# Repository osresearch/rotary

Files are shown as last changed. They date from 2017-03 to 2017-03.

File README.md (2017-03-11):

Outbound call state machine

This is an extension on Adafruit's [`FONAtest.ino`](https://github.com/adafruit/Adafruit_FONA/blob/master/examples/FONAtest/FONAtest.ino)
example code to allow it to be used with a rotary phone.  The Teensy
2.0 decodes the pulses and implements the state machine to allow you to
place outbound phone calls.  In-bound calls are working and can activate
the ringer when on USB power, but the boost converter circuit is a work
in progress.

The dialtone is generated by the FONA and under control of the teensy,
but ringing and dialing is done by the cell network.  There is not a
proper "off hook" tone in the FONA, so the closest version was used.

Since the entire phone number must be passed to the `ATDT` command
string, the system must try to detect when the user is done dialing.
There is currently a multi-second delay after the last number.

During a call pulses will be translated to DTMF, but the user will
not hear them on the handset.  There is also no comfort tone, which
makes using the phone feel "dead".

Wiring
===
Inside the phone

* Teensy Gnd -> FONA Ground, FONA Key, Phone F (blue?)
* Teensy Vcc -> FONA Vio
* Teensy Pin 0 -> FONA Reset
* Teensy Pin 1 -> Phone RR (green on the dial), rotary dial
* Teensy Pin 2 -> Phone L1 (RJ45 green), hook relay
* Teensy Pin 6 -> FONA Ring indicator
* Teensy Pin 7 -> FONA RX
* Teensy Pin 8 -> FONA TX
* Teensy Pin 9 -> boost converter pwm
* Teensy Pin A0 -> boost converter voltge divider

The boost converter circuit needs to be drawn.

Note the [FONA 32u4 pinout](https://learn.adafruit.com/adafruit-feather-32u4-fona/pinouts) is a bit different:

* GPIO 8 -> FONA TXD (Soft Serial)
* GPIO 9 -> FONA RXD (Soft Serial)
* GPIO 7 -> FONA Ring Indicator
* GPIO 4 -> FONA Reset

Todo
===
Dialup internet

* Redial support.
* ~~Incoming call state machine~~ - Done. Incoming calls works (although they play a tone in the speaker)
* ~~Disable headset ring tone.~~ - WONTFIX, since the bell overpowers it quite easily.
* Ringer driver circuit. Looks like 15V will engage the bell solenoid, so a simple charge pump and low frequency PWM should do it. -- Almost done, need to find parameters to work with 3.7V LiPo.
* ~~PCB design to mount FONA, Teensy and wire headers for the phone connections. -- Started in `pcb/rotaryfona.sch`, but no where near ready.~~ On hold since the FONA 32u4 has a MCU built in.
* Package everything to fit into the phone.
* Buy a red phone, cut a hole for USB charging cable.
* Teensy powered from the battery?  Battery switch?
* Figure out why 300 baud isn't working with the FONA as well as it did with my cellphone.
* Text to speech for SMS received - only supported in the 800H, not the 800L.

State Machine
==
Rotary Phone State Machine

The rotary phone code is implemented as a state machine to try to
keep it clean and easy to extend. Unfortunately there isn't an easy way
to round trip from the code to this diagram, so it doesn't exactly match
the executable code in [`Rotary.cpp`](./RotaryFona/Rotary.cpp).
Also, nearly every state other than `RINGING` has an implicit edge
back to `ON_HOOK` if the user hangs up the phone while in that state.

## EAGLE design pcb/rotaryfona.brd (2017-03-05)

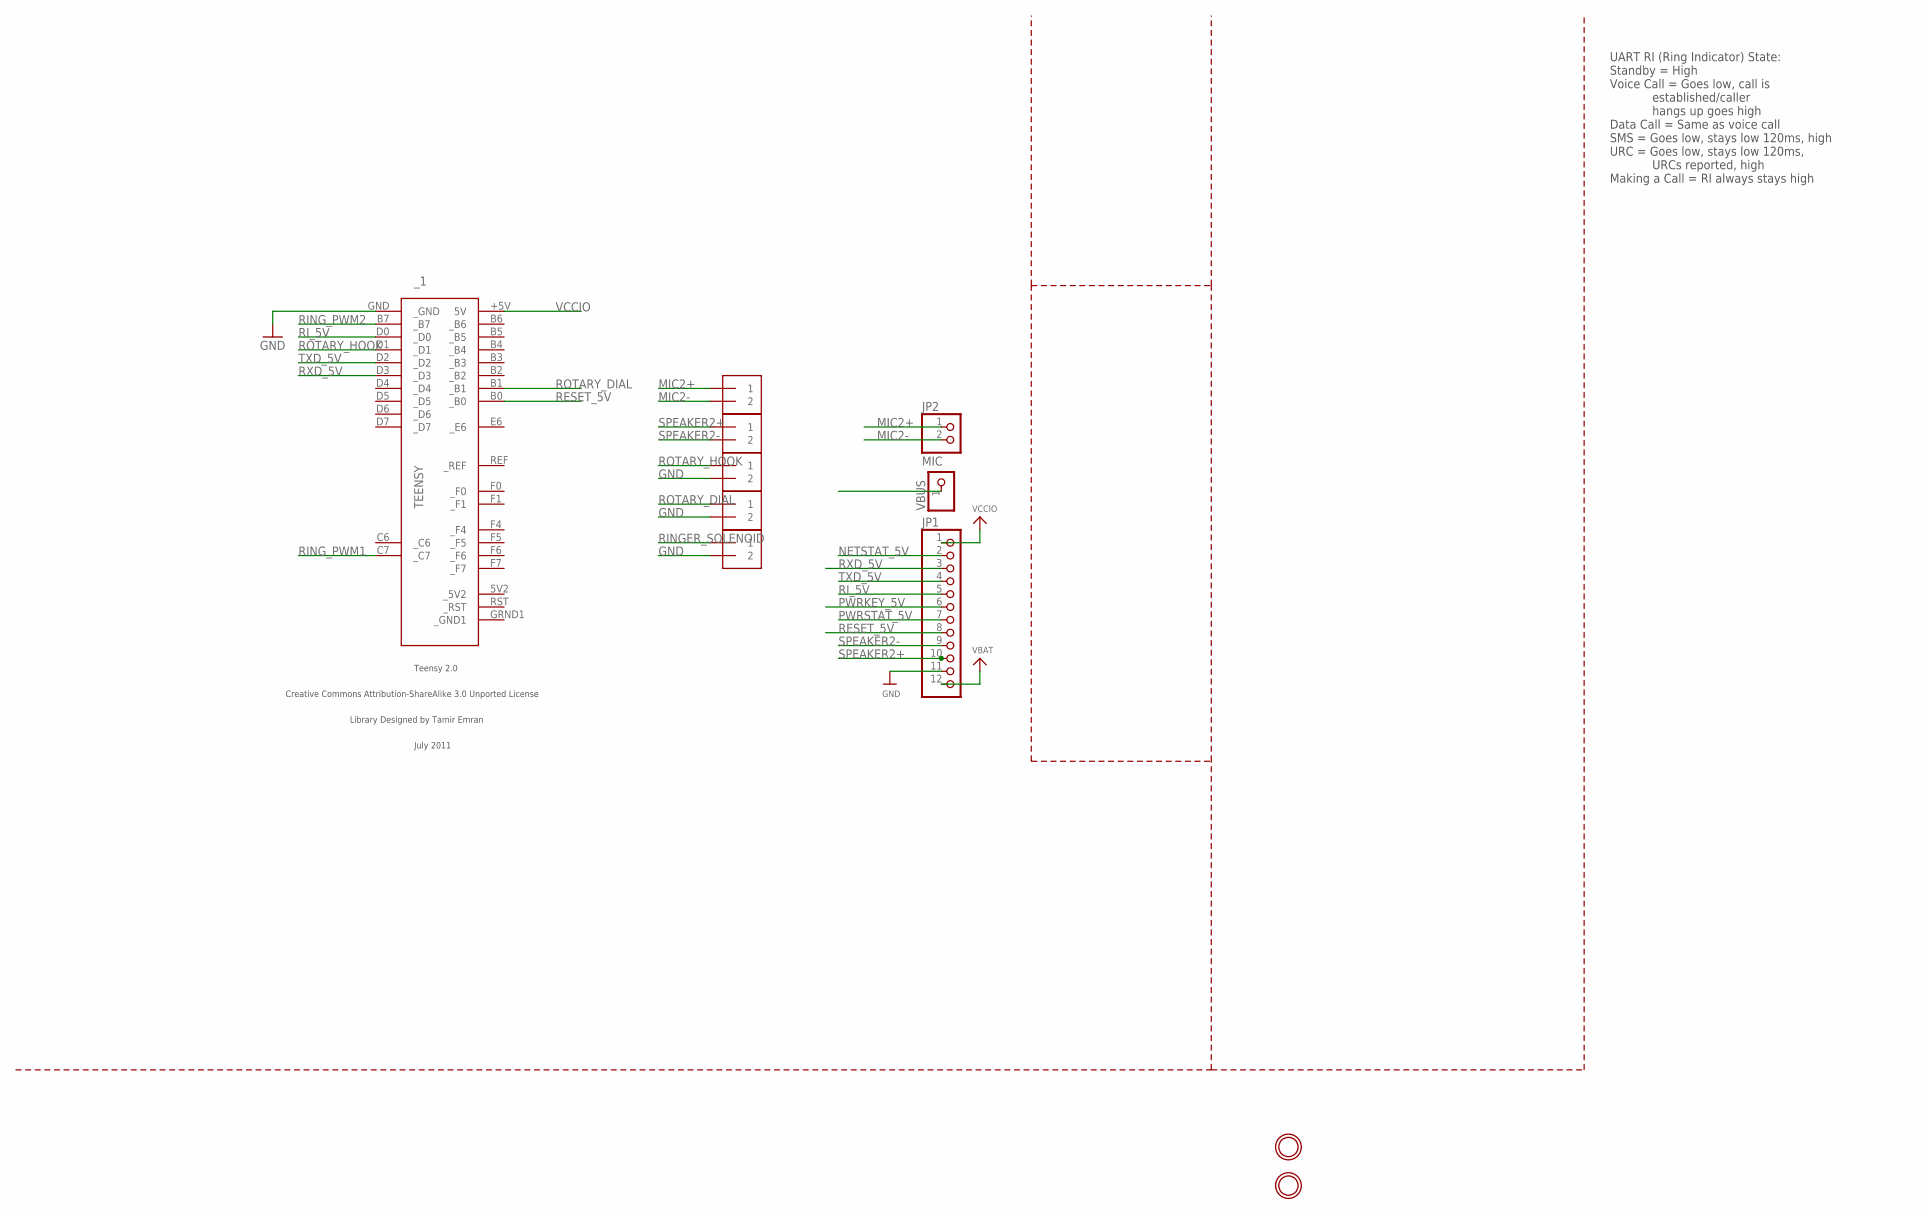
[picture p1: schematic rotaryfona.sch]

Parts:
DIAL: 1X2-3.5MM
HOOK: 1X2-3.5MM
JP1: PINHD-1X12-CB; 1X12-CB
JP2: MIC; 1X02_ROUND
MIC: 1X2-3.5MM
RINGER: 1X2-3.5MM
SPK: 1X2-3.5MM
U$33, U$34: MOUNTINGHOLE2.5; MOUNTINGHOLE_2.5_PLATED
VBUS: PINHD-1X1CB; 1X01-CLEANBIG
_1: TEENSY

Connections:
GND: DIAL.2, HOOK.2, JP1.11, RINGER.2, _1.GND (_GND)
MIC2+: JP2.1, MIC.1
MIC2-: JP2.2, MIC.2
NETSTAT_5V: JP1.2
PWRKEY_5V: JP1.6
PWRSTAT_5V: JP1.7
RESET_5V: JP1.8, _1.B0 (_B0)
RINGER_SOLENOID: RINGER.1
RING_PWM1: _1.C7 (_C7)
RING_PWM2: _1.B7 (_B7)
RI_5V: JP1.5, _1.D0 (_D0)
ROTARY_DIAL: DIAL.1, _1.B1 (_B1)
ROTARY_HOOK: HOOK.1, _1.D1 (_D1)
RXD_5V: JP1.3, _1.D3 (_D3)
SPEAKER2+: JP1.10, SPK.1
SPEAKER2-: JP1.9, SPK.2
TXD_5V: JP1.4, _1.D2 (_D2)
VBAT: JP1.12
VCCIO: JP1.1, _1.+5V (5V)

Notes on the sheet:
UART RI (Ring Indicator) State: Standby = High Voice Call = Goes low, call is established/caller hangs up goes high Data Call = Same as voice call SMS = Goes low, stays low 120ms, high URC = Goes low, stays low 120ms, URCs reported, high Making a Call = RI always stays high

Board: 2 copper layers, 11 parts (0 on the bottom side), 12 nets, no tracks yet.

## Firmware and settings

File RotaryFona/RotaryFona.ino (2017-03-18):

/***************************************************
  This is an extension of Adafruit's FONA example program,
  modified to work with rotary phones like the Bell 500
  and a Teensy microcontroller.

  Designed specifically to work with the Adafruit FONA
  ----> http://www.adafruit.com/products/1946
  ----> http://www.adafruit.com/products/1963
  ----> http://www.adafruit.com/products/2468
  ----> http://www.adafruit.com/products/2542

  These cellular modules use TTL Serial to communicate, 2 pins are
  required to interface
  Adafruit invests time and resources providing this open source code,
  please support Adafruit and open-source hardware by purchasing
  products from Adafruit!

  The rotary phone uses one input pin to detect when the
  handset has gone "off hook" and another to detect the
  pulses of the rotary dial.  The ringer is not yet
  supported.

  Written by Limor Fried/Ladyada for Adafruit Industries
  and Trammell Hudson <hudson@trmm.net>.

  BSD license, all text above must be included in any redistribution
 ****************************************************/

/*
THIS CODE IS STILL IN PROGRESS!

Open up the serial console on the Arduino at 115200 baud to interact with FONA

Note that if you need to set a GPRS APN, username, and password scroll down to
the commented section below at the end of the setup() function.
*/
#include "Adafruit_FONA.h"
#include "Rotary.h"

// Feather Fona 32u4 serial
#define FONA_RX 9
#define FONA_TX 8
#define FONA_RST 4

// this is a large buffer for replies
char replybuffer[255];

// We default to using software serial. If you want to use hardware serial
// (because softserial isnt supported) comment out the following three lines 
// and uncomment the HardwareSerial line
#include <SoftwareSerial.h>
SoftwareSerial fonaSS = SoftwareSerial(FONA_TX, FONA_RX);
SoftwareSerial *fonaSerial = &fonaSS;

// Hardware serial is also possible, but not wired on the
// Feather Fona with the 32u4, so we have to use the software one
//HardwareSerial *fonaSerial = &Serial1;

// Use this for FONA 800 and 808s
Adafruit_FONA fona = Adafruit_FONA(FONA_RST);
// Use this one for FONA 3G
//Adafruit_FONA_3G fona = Adafruit_FONA_3G(FONA_RST);

Rotary rotary(fona);

uint8_t readline(char *buff, uint8_t maxbuff, uint16_t timeout = 0);

uint8_t type;

void setup()
{
#if 0
  // charge pump tuning setup
  rotary.tune();
#else
  rotary.begin();

  //while (!Serial);

  Serial.begin(115200);
  Serial.println(F("FONA basic test"));
  Serial.println(F("Initializing....(May take 3 seconds)"));

  fonaSerial->begin(4800);
  if (! fona.begin(*fonaSerial)) {
    Serial.println(F("Couldn't find FONA"));
    while (1);
  }
  type = fona.type();
  Serial.println(F("FONA is OK"));
  Serial.print(F("Found "));
  switch (type) {
    case FONA800L:
      Serial.println(F("FONA 800L")); break;
    case FONA800H:
      Serial.println(F("FONA 800H")); break;
    case FONA808_V1:
      Serial.println(F("FONA 808 (v1)")); break;
    case FONA808_V2:
      Serial.println(F("FONA 808 (v2)")); break;
    case FONA3G_A:
      Serial.println(F("FONA 3G (American)")); break;
    case FONA3G_E:
      Serial.println(F("FONA 3G (European)")); break;
    default: 
      Serial.println(F("???")); break;
  }
  
  // Print module IMEI number.
  char imei[15] = {0}; // MUST use a 16 character buffer for IMEI!
  uint8_t imeiLen = fona.getIMEI(imei);
  if (imeiLen > 0) {
    Serial.print("Module IMEI: "); Serial.println(imei);
  }

  // Optionally configure a GPRS APN, username, and password.
  // You might need to do this to access your network's GPRS/data
  // network.  Contact your provider for the exact APN, username,
  // and password values.  Username and password are optional and
  // can be removed, but APN is required.
  //fona.setGPRSNetworkSettings(F("your APN"), F("your username"), F("your password"));

  // Optionally configure HTTP gets to follow redirects over SSL.
  // Default is not to follow SSL redirects, however if you uncomment
  // the following line then redirects over SSL will be followed.
  //fona.setHTTPSRedirect(true);


  // setup for the hard wired rotary phone
  fona.setAudio(FONA_EXTAUDIO);
  fona.setMicVolume(FONA_EXTAUDIO, 10);

  printMenu();
#endif
}

void printMenu(void) {
  Serial.println(F("-------------------------------------"));
  Serial.println(F("[?] Print this menu"));
  Serial.println(F("[a] read the ADC 2.8V max (FONA800 & 808)"));
  Serial.println(F("[b] read the Battery V and % charged"));
  Serial.println(F("[C] read the SIM CCID"));
  Serial.println(F("[U] Unlock SIM with PIN code"));
  Serial.println(F("[i] read RSSI"));
  Serial.println(F("[n] get Network status"));
  Serial.println(F("[v] set audio Volume"));
  Serial.println(F("[V] get Volume"));
  Serial.println(F("[H] set Headphone audio (FONA800 & 808)"));
  Serial.println(F("[e] set External audio (FONA800 & 808)"));
  Serial.println(F("[T] play audio Tone"));
  Serial.println(F("[P] PWM/Buzzer out (FONA800 & 808)"));

  // FM (SIM800 only!)
  Serial.println(F("[f] tune FM radio (FONA800)"));
  Serial.println(F("[F] turn off FM (FONA800)"));
  Serial.println(F("[m] set FM volume (FONA800)"));
  Serial.println(F("[M] get FM volume (FONA800)"));
  Serial.println(F("[q] get FM station signal level (FONA800)"));

  // Phone
  Serial.println(F("[c] make phone Call"));
  Serial.println(F("[A] get call status"));
  Serial.println(F("[h] Hang up phone"));
  Serial.println(F("[p] Pick up phone"));

  // SMS
  Serial.println(F("[N] Number of SMSs"));
  Serial.println(F("[r] Read SMS #"));
  Serial.println(F("[R] Read All SMS"));
  Serial.println(F("[d] Delete SMS #"));
  Serial.println(F("[s] Send SMS"));
  Serial.println(F("[u] Send USSD"));
  
  // Time
  Serial.println(F("[y] Enable network time sync (FONA 800 & 808)"));
  Serial.println(F("[Y] Enable NTP time sync (GPRS FONA 800 & 808)"));
  Serial.println(F("[t] Get network time"));

  // GPRS
  Serial.println(F("[G] Enable GPRS"));
  Serial.println(F("[g] Disable GPRS"));
  Serial.println(F("[l] Query GSMLOC (GPRS)"));
  Serial.println(F("[w] Read webpage (GPRS)"));
  Serial.println(F("[W] Post to website (GPRS)"));

  // GPS
  if ((type == FONA3G_A) || (type == FONA3G_E) || (type == FONA808_V1) || (type == FONA808_V2)) {
    Serial.println(F("[O] Turn GPS on (FONA 808 & 3G)"));
    Serial.println(F("[o] Turn GPS off (FONA 808 & 3G)"));
    Serial.println(F("[L] Query GPS location (FONA 808 & 3G)"));
    if (type == FONA808_V1) {
      Serial.println(F("[x] GPS fix status (FONA808 v1 only)"));
    }
    Serial.println(F("[E] Raw NMEA out (FONA808)"));
  }
  
  Serial.println(F("[S] create Serial passthru tunnel"));
  Serial.println(F("-------------------------------------"));
  Serial.println(F(""));

}


void loop() {
  Serial.print(F("FONA> "));
  while (! Serial.available() ) {
    //rotary.loop();

    if (fona.available()) {
      Serial.write(fona.read());
    }
  }

  char command = Serial.read();
  Serial.println(command);


  switch (command) {
    case '?': {
        printMenu();
        break;
      }

    case 'a': {
        // read the ADC
        uint16_t adc;
        if (! fona.getADCVoltage(&adc)) {
          Serial.println(F("Failed to read ADC"));
        } else {
          Serial.print(F("ADC = ")); Serial.print(adc); Serial.println(F(" mV"));
        }
        break;
      }

    case 'b': {
        // read the battery voltage and percentage
        uint16_t vbat;
        if (! fona.getBattVoltage(&vbat)) {
          Serial.println(F("Failed to read Batt"));
        } else {
          Serial.print(F("VBat = ")); Serial.print(vbat); Serial.println(F(" mV"));
        }


        if (! fona.getBattPercent(&vbat)) {
          Serial.println(F("Failed to read Batt"));
        } else {
          Serial.print(F("VPct = ")); Serial.print(vbat); Serial.println(F("%"));
        }

        break;
      }

    case 'U': {
        // Unlock the SIM with a PIN code
        char PIN[5];
        flushSerial();
        Serial.println(F("Enter 4-digit PIN"));
        readline(PIN, 3);
        Serial.println(PIN);
        Serial.print(F("Unlocking SIM card: "));
        if (! fona.unlockSIM(PIN)) {
          Serial.println(F("Failed"));
        } else {
          Serial.println(F("OK!"));
        }
        break;
      }

    case 'C': {
        // read the CCID
        fona.getSIMCCID(replybuffer);  // make sure replybuffer is at least 21 bytes!
        Serial.print(F("SIM CCID = ")); Serial.println(replybuffer);
        break;
      }

    case 'i': {
        // read the RSSI
        uint8_t n = fona.getRSSI();
        int8_t r;

        Serial.print(F("RSSI = ")); Serial.print(n); Serial.print(": ");
        if (n == 0) r = -115;
        if (n == 1) r = -111;
        if (n == 31) r = -52;
        if ((n >= 2) && (n <= 30)) {
          r = map(n, 2, 30, -110, -54);
        }
        Serial.print(r); Serial.println(F(" dBm"));

        break;
      }

    case 'n': {
        // read the network/cellular status
        uint8_t n = fona.getNetworkStatus();
        Serial.print(F("Network status "));
        Serial.print(n);
        Serial.print(F(": "));
        if (n == 0) Serial.println(F("Not registered"));
        if (n == 1) Serial.println(F("Registered (home)"));
        if (n == 2) Serial.println(F("Not registered (searching)"));
        if (n == 3) Serial.println(F("Denied"));
        if (n == 4) Serial.println(F("Unknown"));
        if (n == 5) Serial.println(F("Registered roaming"));
        break;
      }

    /*** Audio ***/
    case 'v': {
        // set volume
        flushSerial();
        if ( (type == FONA3G_A) || (type == FONA3G_E) ) {
          Serial.print(F("Set Vol [0-8] "));
        } else {
          Serial.print(F("Set Vol % [0-100] "));
        }
        uint8_t vol = readnumber();
        Serial.println();
        if (! fona.setVolume(vol)) {
          Serial.println(F("Failed"));
        } else {
          Serial.println(F("OK!"));
        }
        break;
      }

    case 'V': {
        uint8_t v = fona.getVolume();
        Serial.print(v);
        if ( (type == FONA3G_A) || (type == FONA3G_E) ) {
          Serial.println(" / 8");
        } else {
          Serial.println("%");
        }
        break;
      }

    case 'H': {
        // Set Headphone output
        if (! fona.setAudio(FONA_HEADSETAUDIO)) {
          Serial.println(F("Failed"));
        } else {
          Serial.println(F("OK!"));
        }
        fona.setMicVolume(FONA_HEADSETAUDIO, 15);
        break;
      }
    case 'e': {
        // Set External output
        if (! fona.setAudio(FONA_EXTAUDIO)) {
          Serial.println(F("Failed"));
        } else {
          Serial.println(F("OK!"));
        }

        fona.setMicVolume(FONA_EXTAUDIO, 10);
        break;
      }

    case 'T': {
        // play tone
        flushSerial();
        Serial.print(F("Play tone #"));
        uint8_t kittone = readnumber();
        Serial.println();
        // play for 1 second (1000 ms)
        if (! fona.playToolkitTone(kittone, 1000)) {
          Serial.println(F("Failed"));
        } else {
          Serial.println(F("OK!"));
        }
        break;
      }

    /*** FM Radio ***/

    case 'f': {
        // get freq
        flushSerial();
        Serial.print(F("FM Freq (eg 1011 == 101.1 MHz): "));
        uint16_t station = readnumber();
        Serial.println();
        // FM radio ON using headset
        if (fona.FMradio(true, FONA_HEADSETAUDIO)) {
          Serial.println(F("Opened"));
        }
        if (! fona.tuneFMradio(station)) {
          Serial.println(F("Failed"));
        } else {
          Serial.println(F("Tuned"));
        }
        break;
      }
    case 'F': {
        // FM radio off
        if (! fona.FMradio(false)) {
          Serial.println(F("Failed"));
        } else {
          Serial.println(F("OK!"));
        }
        break;
      }
    case 'm': {
        // Set FM volume.
        flushSerial();
        Serial.print(F("Set FM Vol [0-6]:"));
        uint8_t vol = readnumber();
        Serial.println();
        if (!fona.setFMVolume(vol)) {
          Serial.println(F("Failed"));
        } else {
          Serial.println(F("OK!"));
        }
        break;
      }
    case 'M': {
        // Get FM volume.
        uint8_t fmvol = fona.getFMVolume();
        if (fmvol < 0) {
          Serial.println(F("Failed"));
        } else {
          Serial.print(F("FM volume: "));
          Serial.println(fmvol, DEC);
        }
        break;
      }
    case 'q': {
        // Get FM station signal level (in decibels).
        flushSerial();
        Serial.print(F("FM Freq (eg 1011 == 101.1 MHz): "));
        uint16_t station = readnumber();
        Serial.println();
        int8_t level = fona.getFMSignalLevel(station);
        if (level < 0) {
          Serial.println(F("Failed! Make sure FM radio is on (tuned to station)."));
        } else {
          Serial.print(F("Signal level (dB): "));
          Serial.println(level, DEC);
        }
        break;
      }

    /*** PWM ***/

    case 'P': {
        // PWM Buzzer output @ 2KHz max
        flushSerial();
        Serial.print(F("PWM Freq, 0 = Off, (1-2000): "));
        uint16_t freq = readnumber();
        Serial.println();
        if (! fona.setPWM(freq)) {
          Serial.println(F("Failed"));
        } else {
          Serial.println(F("OK!"));
        }
        break;
      }

    /*** Call ***/
    case 'c': {
        // call a phone!
        char number[30];
        flushSerial();
        Serial.print(F("Call #"));
        readline(number, 30);
        Serial.println();
        Serial.print(F("Calling ")); Serial.println(number);
        if (!fona.callPhone(number)) {
          Serial.println(F("Failed"));
        } else {
          Serial.println(F("Sent!"));
        }

        break;
      }
    case 'A': {
        // get call status
        int8_t callstat = fona.getCallStatus();
        switch (callstat) {
          case 0: Serial.println(F("Ready")); break;
          case 1: Serial.println(F("Could not get status")); break;
          case 3: Serial.println(F("Ringing (incoming)")); break;
          case 4: Serial.println(F("Ringing/in progress (outgoing)")); break;
          default: Serial.println(F("Unknown")); break;
        }
        break;
      }
      
    case 'h': {
        // hang up!
        if (! fona.hangUp()) {
          Serial.println(F("Failed"));
        } else {
          Serial.println(F("OK!"));
        }
        break;
      }

    case 'p': {
        // pick up!
        if (! fona.pickUp()) {
          Serial.println(F("Failed"));
        } else {
          Serial.println(F("OK!"));
        }
        break;
      }

    /*** SMS ***/

    case 'N': {
        // read the number of SMS's!
        int8_t smsnum = fona.getNumSMS();
        if (smsnum < 0) {
          Serial.println(F("Could not read # SMS"));
        } else {
          Serial.print(smsnum);
          Serial.println(F(" SMS's on SIM card!"));
        }
        break;
      }
    case 'r': {
        // read an SMS
        flushSerial();
        Serial.print(F("Read #"));
        uint8_t smsn = readnumber();
        Serial.print(F("\n\rReading SMS #")); Serial.println(smsn);

        // Retrieve SMS sender address/phone number.
        if (! fona.getSMSSender(smsn, replybuffer, 250)) {
          Serial.println("Failed!");
          break;
        }
        Serial.print(F("FROM: ")); Serial.println(replybuffer);

        // Retrieve SMS value.
        uint16_t smslen;
        if (! fona.readSMS(smsn, replybuffer, 250, &smslen)) { // pass in buffer and max len!
          Serial.println("Failed!");
          break;
        }
        Serial.print(F("***** SMS #")); Serial.print(smsn);
        Serial.print(" ("); Serial.print(smslen); Serial.println(F(") bytes *****"));
        Serial.println(replybuffer);
        Serial.println(F("*****"));

        break;
      }
    case 'R': {
        // read all SMS
        int8_t smsnum = fona.getNumSMS();
        uint16_t smslen;
        int8_t smsn;

        if ( (type == FONA3G_A) || (type == FONA3G_E) ) {
          smsn = 0; // zero indexed
          smsnum--;
        } else {
          smsn = 1;  // 1 indexed
        }

        for ( ; smsn <= smsnum; smsn++) {
          Serial.print(F("\n\rReading SMS #")); Serial.println(smsn);
          if (!fona.readSMS(smsn, replybuffer, 250, &smslen)) {  // pass in buffer and max len!
            Serial.println(F("Failed!"));
            break;
          }
          // if the length is zero, its a special case where the index number is higher
          // so increase the max we'll look at!
          if (smslen == 0) {
            Serial.println(F("[empty slot]"));
            smsnum++;
            continue;
          }

          Serial.print(F("***** SMS #")); Serial.print(smsn);
          Serial.print(" ("); Serial.print(smslen); Serial.println(F(") bytes *****"));
          Serial.println(replybuffer);
          Serial.println(F("*****"));
        }
        break;
      }

    case 'd': {
        // delete an SMS
        flushSerial();
        Serial.print(F("Delete #"));
        uint8_t smsn = readnumber();

        Serial.print(F("\n\rDeleting SMS #")); Serial.println(smsn);
        if (fona.deleteSMS(smsn)) {
          Serial.println(F("OK!"));
        } else {
          Serial.println(F("Couldn't delete"));
        }
        break;
      }

    case 's': {
        // send an SMS!
        char sendto[21], message[141];
        flushSerial();
        Serial.print(F("Send to #"));
        readline(sendto, 20);
        Serial.println(sendto);
        Serial.print(F("Type out one-line message (140 char): "));
        readline(message, 140);
        Serial.println(message);
        if (!fona.sendSMS(sendto, message)) {
          Serial.println(F("Failed"));
        } else {
          Serial.println(F("Sent!"));
        }

        break;
      }

    case 'u': {
      // send a USSD!
      char message[141];
      flushSerial();
      Serial.print(F("Type out one-line message (140 char): "));
      readline(message, 140);
      Serial.println(message);

      uint16_t ussdlen;
      if (!fona.sendUSSD(message, replybuffer, 250, &ussdlen)) { // pass in buffer and max len!
        Serial.println(F("Failed"));
      } else {
        Serial.println(F("Sent!"));
        Serial.print(F("***** USSD Reply"));
        Serial.print(" ("); Serial.print(ussdlen); Serial.println(F(") bytes *****"));
        Serial.println(replybuffer);
        Serial.println(F("*****"));
      }
    }

    /*** Time ***/

    case 'y': {
        // enable network time sync
        if (!fona.enableNetworkTimeSync(true))
          Serial.println(F("Failed to enable"));
        break;
      }

    case 'Y': {
        // enable NTP time sync
        if (!fona.enableNTPTimeSync(true, F("pool.ntp.org")))
          Serial.println(F("Failed to enable"));
        break;
      }

    case 't': {
        // read the time
        char buffer[23];

        fona.getTime(buffer, 23);  // make sure replybuffer is at least 23 bytes!
        Serial.print(F("Time = ")); Serial.println(buffer);
        break;
      }


    /*********************************** GPS (SIM808 only) */

    case 'o': {
        // turn GPS off
        if (!fona.enableGPS(false))
          Serial.println(F("Failed to turn off"));
        break;
      }
    case 'O': {
        // turn GPS on
        if (!fona.enableGPS(true))
          Serial.println(F("Failed to turn on"));
        break;
      }
    case 'x': {
        int8_t stat;
        // check GPS fix
        stat = fona.GPSstatus();
        if (stat < 0)
          Serial.println(F("Failed to query"));
        if (stat == 0) Serial.println(F("GPS off"));
        if (stat == 1) Serial.println(F("No fix"));
        if (stat == 2) Serial.println(F("2D fix"));
        if (stat == 3) Serial.println(F("3D fix"));
        break;
      }

    case 'L': {
        // check for GPS location
        char gpsdata[120];
        fona.getGPS(0, gpsdata, 120);
        if (type == FONA808_V1)
          Serial.println(F("Reply in format: mode,longitude,latitude,altitude,utctime(yyyymmddHHMMSS),ttff,satellites,speed,course"));
        else 
          Serial.println(F("Reply in format: mode,fixstatus,utctime(yyyymmddHHMMSS),latitude,longitude,altitude,speed,course,fixmode,reserved1,HDOP,PDOP,VDOP,reserved2,view_satellites,used_satellites,reserved3,C/N0max,HPA,VPA"));
        Serial.println(gpsdata);

        break;
      }

    case 'E': {
        flushSerial();
        if (type == FONA808_V1) {
          Serial.print(F("GPS NMEA output sentences (0 = off, 34 = RMC+GGA, 255 = all)"));
        } else {
          Serial.print(F("On (1) or Off (0)? "));
        }
        uint8_t nmeaout = readnumber();

        // turn on NMEA output
        fona.enableGPSNMEA(nmeaout);

        break;
      }

    /*********************************** GPRS */

    case 'g': {
        // turn GPRS off
        if (!fona.enableGPRS(false))
          Serial.println(F("Failed to turn off"));
        break;
      }
    case 'G': {
        // turn GPRS on
        if (!fona.enableGPRS(true))
          Serial.println(F("Failed to turn on"));
        break;
      }
    case 'l': {
        // check for GSMLOC (requires GPRS)
        uint16_t returncode;

        if (!fona.getGSMLoc(&returncode, replybuffer, 250))
          Serial.println(F("Failed!"));
        if (returncode == 0) {
          Serial.println(replybuffer);
        } else {
          Serial.print(F("Fail code #")); Serial.println(returncode);
        }

        break;
      }
    case 'w': {
        // read website URL
        uint16_t statuscode;
        int16_t length;
        char url[80];
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

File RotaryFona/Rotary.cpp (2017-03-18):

/** \file
 * Rotary phone state machine.
 *
 * Designed specifically to work with the Adafruit FONA
 *
 * The rotary phone uses one input pin to detect when the
 * handset has gone "off hook" and another to detect the
 * pulses of the rotary dial.  The ringer is not yet
 * supported.
 * 
 * BSD license, all text above must be included in any redistribution
 */

#include <Arduino.h>
#include "Rotary.h"

///// XXX: TODO need to make this use TimerOne now that we're using pin 11
#include "TimerThree.h"

// todo move this into the constructor
#define PULSE_DIAL	1 // rotary pin, normally closed
#define PULSE_HOOK	2 // off hook == 0, on hook == 1
#define PULSE_RING	6 // from the fona, when there is an incoming call
#define ROTARY_PWM	11 // pwm output for charge pump
#define ROTARY_RINGER	A1 // mosfet to dump voltage to the ringer

typedef enum {
	ROTARY_INIT	= 0,
	ROTARY_ONHOOK,
	ROTARY_ONHOOK_CHECK_STATUS,
	ROTARY_RINGING,
	ROTARY_RINGING_WAIT,
	ROTARY_ANSWERED,
	ROTARY_PLAY_DIALTONE,
	ROTARY_WAIT_FIRST_PULSE,
	ROTARY_PLAY_ERRTONE,
	ROTARY_WAIT_ONHOOK,
	ROTARY_PULSE_COUNT = 100,
	ROTARY_PULSE_FALLING,
	ROTARY_PULSE_IGNORE,
	ROTARY_PULSE_WAIT,
	ROTARY_ADD_DIGIT,
	ROTARY_DIAL_NUMBER,
	ROTARY_ON_CALL = 200,
	ROTARY_CALL_PULSE_COUNT,
	ROTARY_CALL_PULSE_FALLING,
	ROTARY_CALL_PULSE_IGNORE,
	ROTARY_CALL_PULSE_WAIT,
	ROTARY_CALL_DIAL_DIGIT,
	ROTARY_CALL_CHECK_STATUS,
	ROTARY_CALL_OVER,
} rotary_state_t;


void Rotary::begin()
{
	// Pull up on the rotary pulse pins
	pinMode(PULSE_DIAL, INPUT_PULLUP);
	pinMode(PULSE_HOOK, INPUT_PULLUP);
	pinMode(PULSE_RING, INPUT_PULLUP);

	// charge pump ringer parameters
	//Timer3.initialize(12); // microsecond pulse width
	pwm = 0;
	ringer_voltage = 400;

	// disable the ringer mosfet
	pinMode(ROTARY_RINGER, OUTPUT);
	digitalWrite(ROTARY_RINGER, 0);

	// disable the pwm charge pump mosfet
	pinMode(ROTARY_PWM, OUTPUT);
	digitalWrite(ROTARY_PWM, 0);

	new_state(ROTARY_INIT);
}

int Rotary::new_state(int new_state_val)
{
	if (state == new_state_val)
		return 0;

	state = new_state_val;
	last_transition = millis();

	Serial.print(last_transition);
	Serial.print(" state=");
	Serial.println(state);
	return state;
}


void Rotary::play_tone(int tone, int len)
{
	fona.playToolkitTone(tone, len);
}

void Rotary::stop_tone()
{
	fona.sendCheckReply(F("AT+STTONE=0"), F("OK"));
}

int Rotary::onhook()
{
	return digitalRead(PULSE_HOOK) != 0;
}

int Rotary::dial()
{
	return digitalRead(PULSE_DIAL) != 0;
}

int Rotary::ring()
{
	return digitalRead(PULSE_RING) == 0;
}

void Rotary::loop()
{
	state_machine();
}


void Rotary::bell(int state)
{
	digitalWrite(ROTARY_RINGER, state);
}


void Rotary::charge_pump(
	unsigned target
)
{
	const unsigned max_pwm = 990;
	const unsigned min_pwm = 100;

	if (target == 0)
	{
		// disable the charge pump, close the output
		//Timer3.pwm(ROTARY_PWM, 0);
		digitalWrite(ROTARY_RINGER, 0);
		pwm = 0;
		return;
	}

	if (pwm == 0)
	{
		// enable the PWM and pre-charge the pump for some time
		pwm = 512;
		pinMode(ROTARY_RINGER, OUTPUT);
		digitalWrite(ROTARY_RINGER, 0);
		//Timer3.pwm(ROTARY_PWM, pwm);
		return;
	}

	
	// read the current value and compare it to our target
	// if we are above the target, shorten the pwm
	// if we are below the target, increase it
	const unsigned val = analogRead(0);
	if (val > target)
	{
		pwm = pwm - (pwm - min_pwm)/2;
	} else {
		pwm = pwm + (max_pwm - pwm)/2;
	}

	//Timer3.pwm(ROTARY_PWM, pwm);
}


int Rotary::state_machine(void)
{
	// compute the time since last transition
	const uint32_t now = millis();
	const uint32_t delta = now - last_transition;

	// all states have a reset when we go back on hook
	// except for the ringing states
	if(onhook()
	&& state != ROTARY_ONHOOK
	&& state != ROTARY_ONHOOK_CHECK_STATUS
	&& state != ROTARY_RINGING
	&& state != ROTARY_RINGING_WAIT)
	{
		charge_pump(0);
		stop_tone();
		fona.hangUp();
		new_state(ROTARY_ONHOOK);
	}

	switch(state)
	{
	case ROTARY_INIT:
		if(!onhook())
			new_state(ROTARY_PLAY_ERRTONE);
		return 0;

	default:
	case ROTARY_ONHOOK:
		pulses = 0;
		digits = 0;
		bell_count = 0;

		if(!onhook())
			return new_state(ROTARY_PLAY_DIALTONE);

		if(ring())
		{
			bell(1);
			return new_state(ROTARY_RINGING);
		}

		return 0;

	case ROTARY_RINGING:
		// If they pick up the phone, go to answered state
		if (!onhook())
			return new_state(ROTARY_ANSWERED);

		// if the phone stops ringing, go back to the
		// onhook state
		if (!ring())
		{
			charge_pump(0);
			return new_state(ROTARY_ONHOOK);
		}

		charge_pump(ringer_voltage);

		if (delta < 40)
			return 0;

		// alternate on and off to pulse the bell
		last_transition = now;
		bell(bell_count & 1);
		if (bell_count++ < 50)
			return 0;

		bell_count = 0;
		return new_state(ROTARY_RINGING_WAIT);

	case ROTARY_RINGING_WAIT:
		// this is the second of silence between rings
		// If they pick up the phone, go to answered state
		if (!onhook())
			return new_state(ROTARY_ANSWERED);

		// if the phone stops ringing, go back to the
		// onhook state
		if (!ring())
		{
			charge_pump(0);
			return new_state(ROTARY_ONHOOK);
		}

		charge_pump(ringer_voltage);

		if (delta < 800)
			return 0;

		// resume the bell
		bell(1);
		return new_state(ROTARY_RINGING);

	case ROTARY_ANSWERED:
		// disable the PWM for the charge pump
		// and turn off the external ringer.
		charge_pump(0);
		stop_tone();
		fona.pickUp();
		return new_state(ROTARY_ON_CALL);

	case ROTARY_PLAY_DIALTONE:
		play_tone(20, 10000);
		return new_state(ROTARY_WAIT_FIRST_PULSE);

	case ROTARY_PLAY_ERRTONE:
		play_tone(2, 10000);
		return new_state(ROTARY_WAIT_ONHOOK);

	case ROTARY_WAIT_ONHOOK:
		// literally do nothing until we go on hook
		return 0;

	case ROTARY_WAIT_FIRST_PULSE:
		// if they have been off hook for too long, error out
		if (delta > 10000)
			return new_state(ROTARY_PLAY_ERRTONE);

		if (!dial())
			return 0;

		// they have started dialing, switch states (to keep the
		// timer correct), then stop the dial tone
		new_state(ROTARY_PULSE_COUNT);
		stop_tone();
		return 0;

	case ROTARY_PULSE_COUNT:
		pulses++;

		// if we get too many pulses, abort this call
		if (pulses > 10)
			return new_state(ROTARY_PLAY_ERRTONE);

		return new_state(ROTARY_PULSE_IGNORE);

	case ROTARY_PULSE_IGNORE:
		if (delta < 15)
			return 0;
		return new_state(ROTARY_PULSE_FALLING);

	case ROTARY_PULSE_FALLING:
		// wait for the falling edge of the transition
		if (!dial())
			return new_state(ROTARY_PULSE_WAIT);
		return 0;

	case ROTARY_PULSE_WAIT:
		// if they spin the dial, start counting again
		if (dial())
			return new_state(ROTARY_PULSE_COUNT);

		// short timeout if we have received pulses,
		// in which case this is a new digit.
		if (delta > 200 && pulses != 0)
			return new_state(ROTARY_ADD_DIGIT);

		// long timeout if we have no pulses, in which case
		// we have the entire number and call dial it
		if (delta > 3000)
			return new_state(ROTARY_DIAL_NUMBER);
		return 0;
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

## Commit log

2017-03-04 Implemented rotary phone logic as a state machine.
    All states work, except for the initial dial which
    seems to have issues if the dialtone is still playing
    due to the adafruit library taking CPU time away.
    [RotaryFona.ino]
2017-03-04 remove prototype code
2017-03-05 document wiring
2017-03-05 started on PCB, importing from adafruit fona board design
    [rotaryfona.brd, rotaryfona.sch]
2017-03-05 Timer3 based boost converter to drive the phone ringer (not yet functional)
2017-03-05 Ringer circuit works.
    This uses the PWM on timer3 to pin9, which allows us to have a 100 KHz
    PWM output to the ringer. We've also used the FONA ring indicator
    pin instead of polling the status, which gives us a faster response
    and might allow us to sleep while waiting for calls.
2017-03-06 tweak timings for boost converter, still does not work on battery
    [Rotary.cpp, RotaryFona.ino]
2017-03-07 dual MOSFET tests generate 35V from 5V with 47uH coil at 2usec/934ticks
2017-03-07 improve low voltage charge pump by allow more charge time
2017-03-10 move charge pump code into the ringer logic. seems to work!
2017-03-18 separate tuning module, update wiring for feather fona

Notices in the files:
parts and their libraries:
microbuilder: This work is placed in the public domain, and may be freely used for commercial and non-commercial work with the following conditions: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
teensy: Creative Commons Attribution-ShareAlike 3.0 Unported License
